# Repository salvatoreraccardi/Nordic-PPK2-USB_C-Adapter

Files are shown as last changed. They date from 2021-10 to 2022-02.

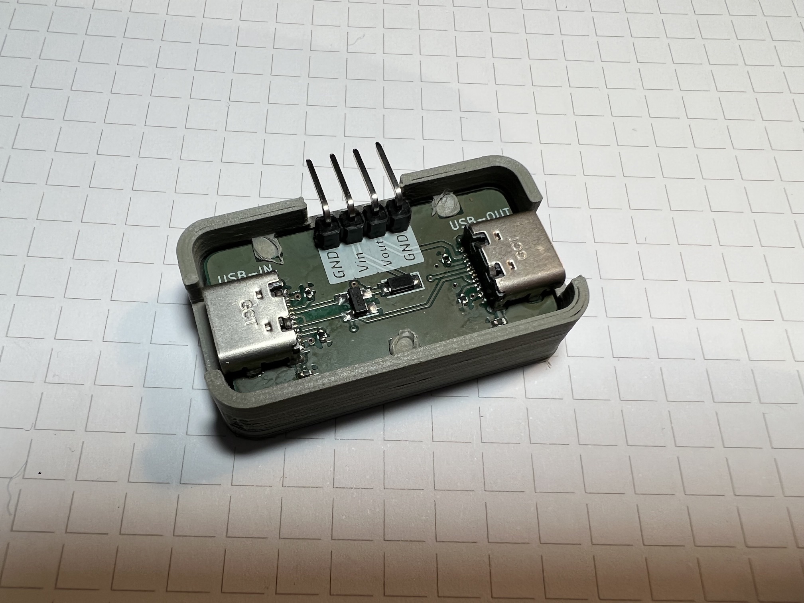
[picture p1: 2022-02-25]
Enclosure/USB-C Power Meter.jpeg

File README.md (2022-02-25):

# Nordic-PPK2-USB_C-Adapter
USB-C adapter for [Nordic's Power Profiler Kit II](https://www.nordicsemi.com/Products/Development-hardware/Power-Profiler-Kit-2). Ideal for easily measuring the current drawn by a device/board.

## Enclosure
The enclosure can be printed using regular PLA. An infill of 100% is recommended.

After mounting the PCB in the enclosure, use a hot flat object (e.g. an iron) to melt the plastic 'pins'. This will lock the PCB in place.

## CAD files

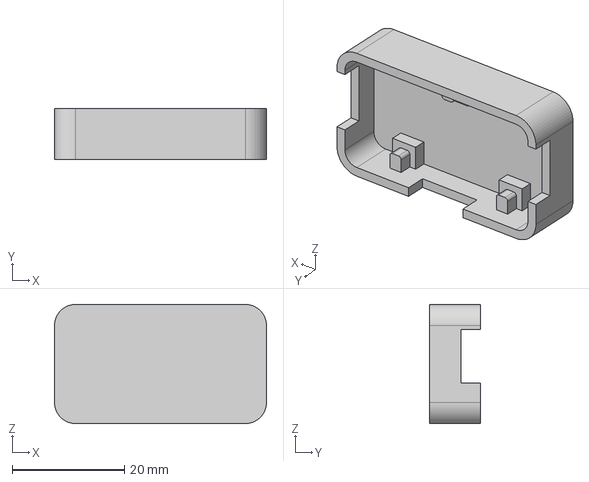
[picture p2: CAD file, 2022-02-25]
Enclosure/USB-C Power Meter.step
37.7 x 9.00 x 21.2 mm

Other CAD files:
Enclosure/USB-C Power Meter.stl

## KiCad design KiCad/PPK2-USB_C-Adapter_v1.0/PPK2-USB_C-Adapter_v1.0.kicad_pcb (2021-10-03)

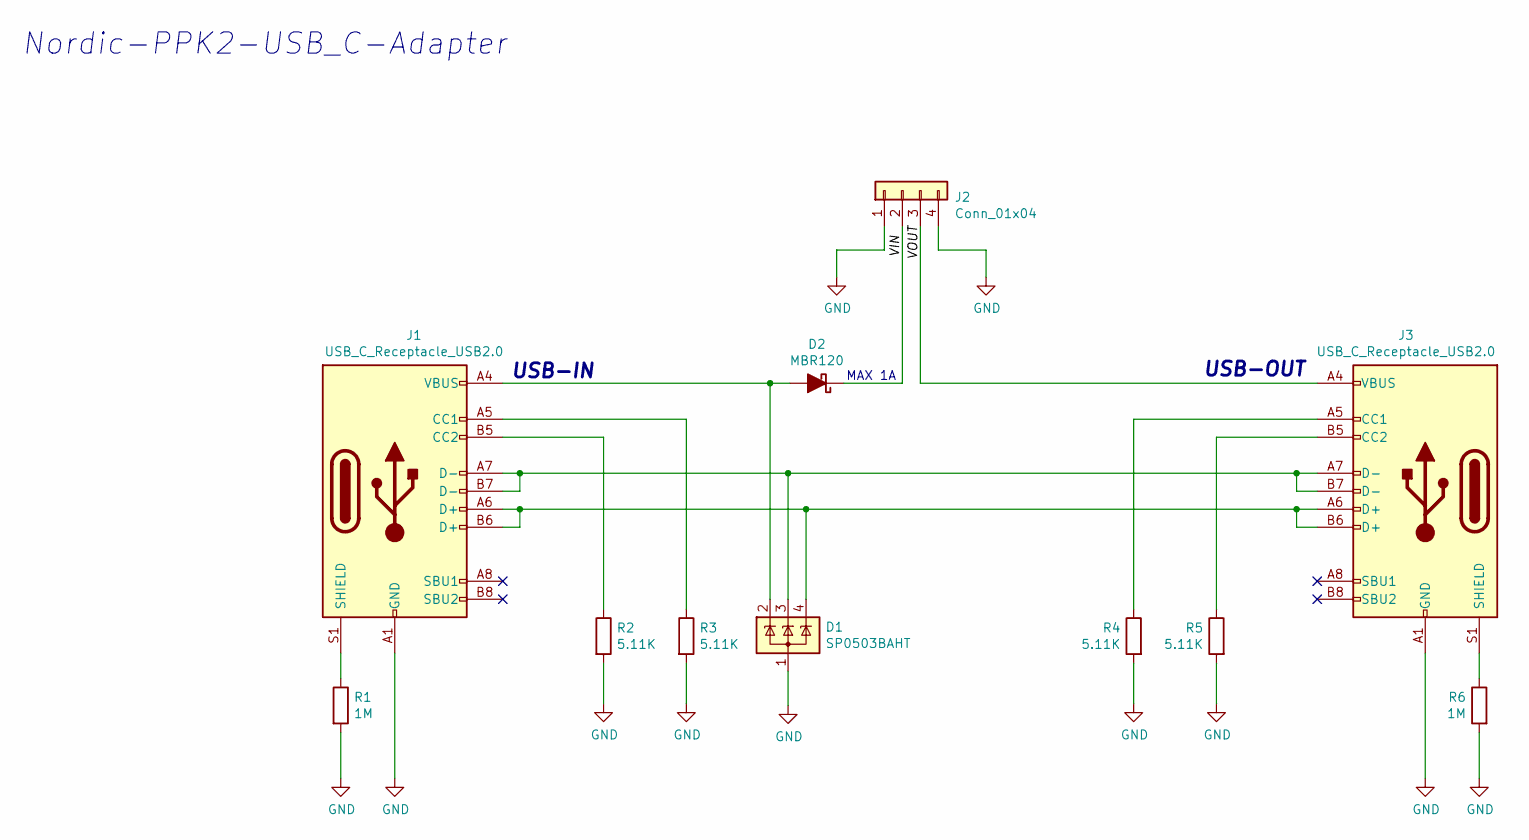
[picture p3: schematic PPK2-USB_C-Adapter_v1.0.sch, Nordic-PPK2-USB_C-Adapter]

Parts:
D1: SP0503BAHT; SOT-143
D2: MBR120; D_SOD-123
J1, J3: USB_C_Receptacle_USB2.0; USB_C_Receptacle_Palconn_UTC16-G
J2: Conn_01x04; PinHeader_1x04_P2.54mm_Vertical
R1, R6: 1M; R_0402_1005Metric
R2, R3, R4, R5: 5.11K; R_0402_1005Metric

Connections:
/VIN: D2.1 (K), J2.2
/VOUT: J2.3, J3.A4 (VBUS), J3.A9 (VBUS), J3.B4 (VBUS), J3.B9 (VBUS)
GND: D1.1 (A), J1.A1 (GND), J1.A12 (GND), J1.B1 (GND), J1.B12 (GND), J2.1, J2.4, J3.A1 (GND), J3.A12 (GND), J3.B1 (GND), J3.B12 (GND), R1.2, R2.2, R3.2, R4.2, R5.2, R6.2
unnamed: D1.2 (K), D2.2 (A), J1.A4 (VBUS), J1.A9 (VBUS), J1.B4 (VBUS), J1.B9 (VBUS)
unnamed: D1.3 (K), J1.A7 (D-), J1.B7 (D-), J3.A7 (D-), J3.B7 (D-)
unnamed: D1.4 (K), J1.A6 (D+), J1.B6 (D+), J3.A6 (D+), J3.B6 (D+)
unnamed: J1.A5 (CC1), R3.1
unnamed: J1.B5 (CC2), R2.1
unnamed: J1.S1 (SHIELD), R1.1
unnamed: J3.A5 (CC1), R4.1
unnamed: J3.B5 (CC2), R5.1
unnamed: J3.S1 (SHIELD), R6.1

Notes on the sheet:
USB-IN
USB-OUT
MAX 1A
Nordic-PPK2-USB_C-Adapter

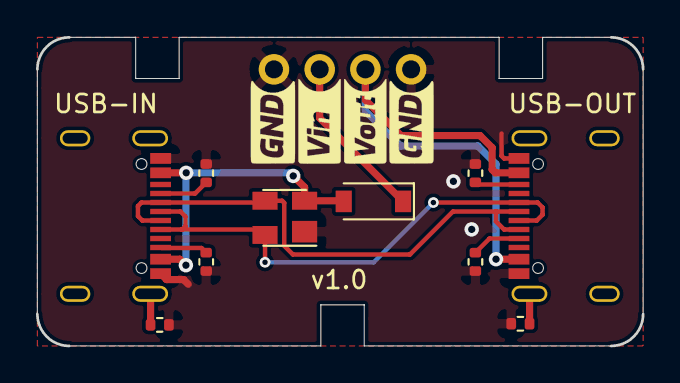
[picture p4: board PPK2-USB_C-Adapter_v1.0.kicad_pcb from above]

Board: 2 copper layers, 33.7 x 17.1 mm, 11 parts (0 on the bottom side), 12 nets.

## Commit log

2021-10-03 last update - gerber
    [PPK2-USB_C-Adapter_v1.0-B_Cu.gbl, PPK2-USB_C-Adapter_v1.0-B_Mask.gbs, PPK2-USB_C-Adapter_v1.0-B_SilkS.gbo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]
2021-10-06 updated silkscreen
    [PPK2-USB_C-Adapter_v1.0.kicad_pcb]
2022-02-25 Add enclosure.
    [USB-C Power Meter.step, USB-C Power Meter.stl]
